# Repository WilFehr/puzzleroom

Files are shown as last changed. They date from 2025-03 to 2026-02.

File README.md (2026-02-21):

# puzzleroom
Inspired by a DND puzzle room where the solution is to be patient and let the timer tick to zero

# what is in this repo?
this repo was started quite late in the development process so was created with the some of the files that will be in the final project

# next step
This project is complete!

# purpose 
the purpose of this project was to:
- gain practial circuit board development experience using KiCad,
- gain more 3D modeling experience using Solidworks
- gain familiarity with the Arduino IDE

# key take aways
I've learned many things from this experience, such as:
- the importance of test points in PCB manufacturing;
  - at some point one LED blew out and it took me a while to figure out that that was the issue and not some other hardware/software issue, having easy access to key circuit points would have made this much faster
- the iterative design nature in engineering;
  - I had many test breadboard circuits before I set up the schematic in KiCad
  - I had many test prints of the base of the housing before I had a design that worked and I was satisfied with.

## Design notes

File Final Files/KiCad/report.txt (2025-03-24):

Info: Processing symbol 'A1:Module:Arduino_Nano'.
Info: Processing symbol 'BZ1:Buzzer_Beeper:Buzzer_12x9.5RM7.6'.
Info: Processing symbol 'D1:LED_THT:LED_D5.0mm_IRGrey'.
Info: Processing symbol 'D2:LED_THT:LED_D5.0mm_IRGrey'.
Info: Processing symbol 'D3:LED_THT:LED_D5.0mm_IRGrey'.
Info: Processing symbol 'D4:LED_THT:LED_D5.0mm_IRGrey'.
Info: Processing symbol 'J1:PPTC021LFBN_RC:CONN2_LFBN-RC_SUL'.
Info: Processing symbol 'R1:Resistor_THT:R_Axial_DIN0207_L6.3mm_D2.5mm_P10.16mm_Horizontal'.
Info: Processing symbol 'R2:Resistor_THT:R_Axial_DIN0207_L6.3mm_D2.5mm_P10.16mm_Horizontal'.
Info: Processing symbol 'R3:Resistor_THT:R_Axial_DIN0207_L6.3mm_D2.5mm_P10.16mm_Horizontal'.
Info: Processing symbol 'R4:Resistor_THT:R_Axial_DIN0207_L6.3mm_D2.5mm_P10.16mm_Horizontal'.
Info: Processing symbol 'R5:Resistor_THT:R_Axial_DIN0207_L6.3mm_D2.5mm_P10.16mm_Horizontal'.
Info: Processing symbol 'R6:Resistor_THT:R_Axial_DIN0207_L6.3mm_D2.5mm_P10.16mm_Horizontal'.
Info: Processing symbol 'SW1:Button_Switch_THT:SW_PUSH_6mm'.
Add A1 (footprint 'Module:Arduino_Nano').
Add BZ1 (footprint 'Buzzer_Beeper:Buzzer_12x9.5RM7.6').
Add D1 (footprint 'LED_THT:LED_D5.0mm_IRGrey').
Add D2 (footprint 'LED_THT:LED_D5.0mm_IRGrey').
Add D3 (footprint 'LED_THT:LED_D5.0mm_IRGrey').
Add D4 (footprint 'LED_THT:LED_D5.0mm_IRGrey').
Add J1 (footprint 'PPTC021LFBN_RC:CONN2_LFBN-RC_SUL').
Add R1 (footprint 'Resistor_THT:R_Axial_DIN0207_L6.3mm_D2.5mm_P10.16mm_Horizontal').
Add R2 (footprint 'Resistor_THT:R_Axial_DIN0207_L6.3mm_D2.5mm_P10.16mm_Horizontal').
Add R3 (footprint 'Resistor_THT:R_Axial_DIN0207_L6.3mm_D2.5mm_P10.16mm_Horizontal').
Add R4 (footprint 'Resistor_THT:R_Axial_DIN0207_L6.3mm_D2.5mm_P10.16mm_Horizontal').
Add R5 (footprint 'Resistor_THT:R_Axial_DIN0207_L6.3mm_D2.5mm_P10.16mm_Horizontal').
Add R6 (footprint 'Resistor_THT:R_Axial_DIN0207_L6.3mm_D2.5mm_P10.16mm_Horizontal').
Add SW1 (footprint 'Button_Switch_THT:SW_PUSH_6mm').

Info: Total warnings: 0, errors: 0.

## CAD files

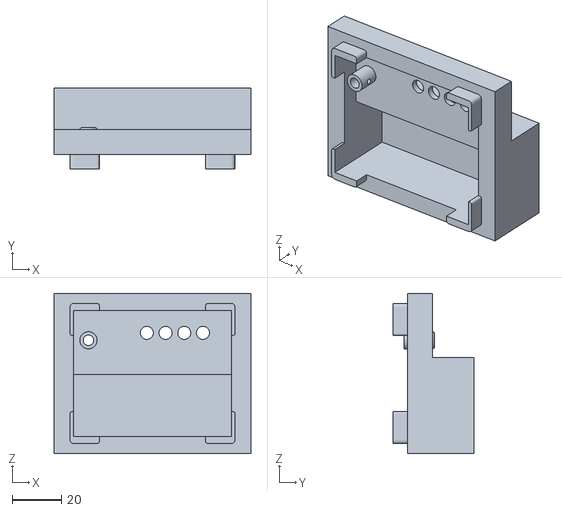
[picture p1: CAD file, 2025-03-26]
STLs/housinglid_complete_draft_V1.STL
80.0 x 33.0 x 65.0

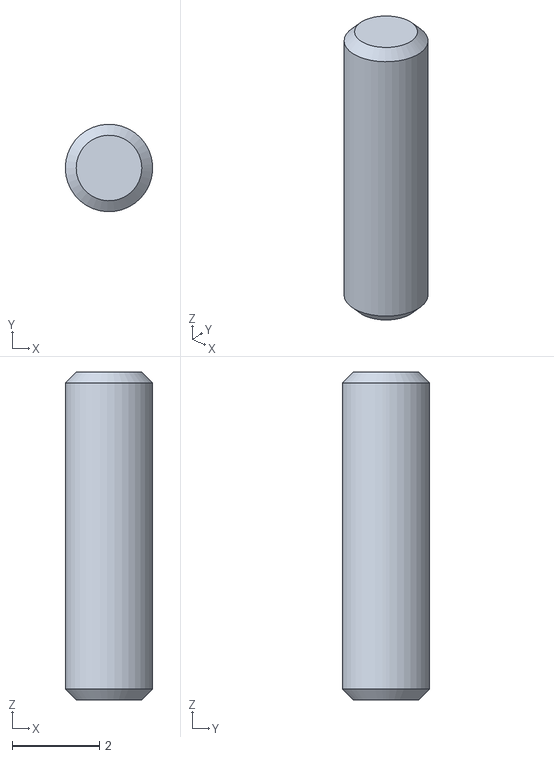
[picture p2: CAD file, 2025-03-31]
Final Files/STLs/locking_peg_FINAL.STL
2.00 x 2.00 x 7.50

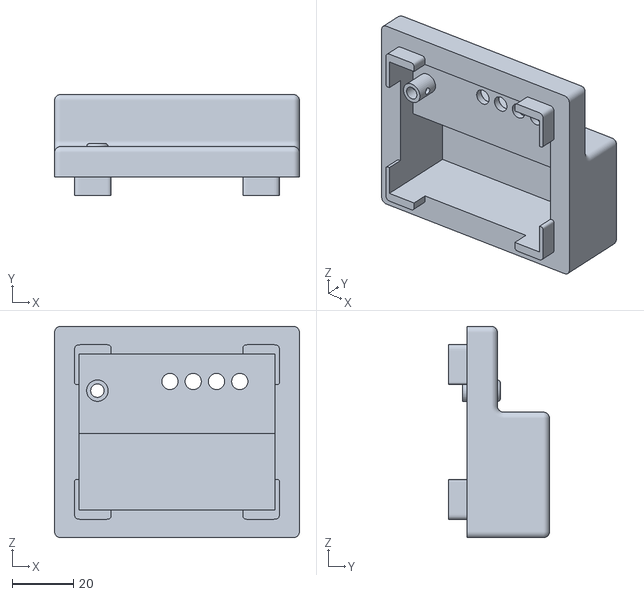
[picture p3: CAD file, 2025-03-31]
Final Files/STLs/housinglid_FINAL.STL
80.0 x 33.0 x 69.0

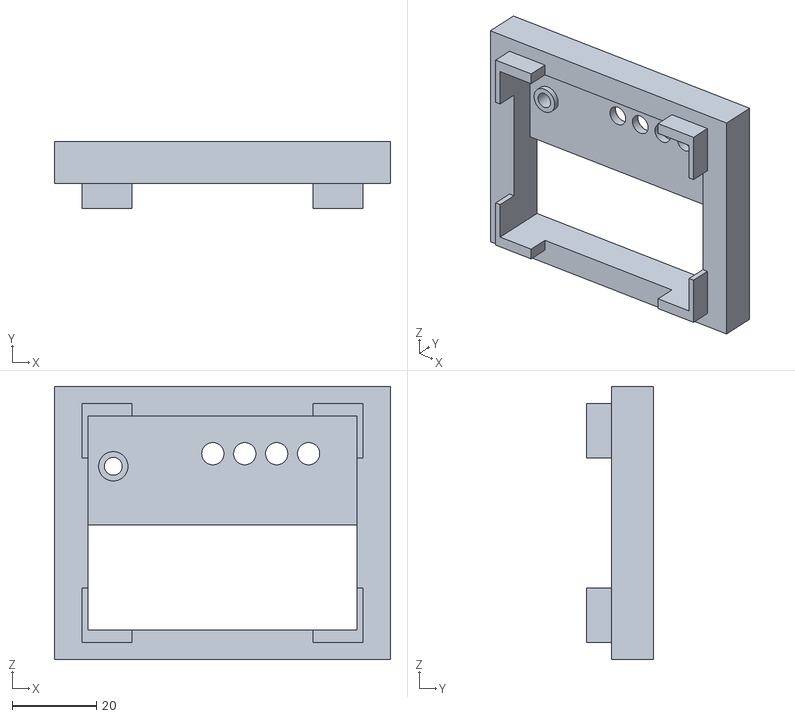
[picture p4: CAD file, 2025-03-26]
STLs/housinglid_lock_check_V2.STL
80.0 x 16.0 x 65.0

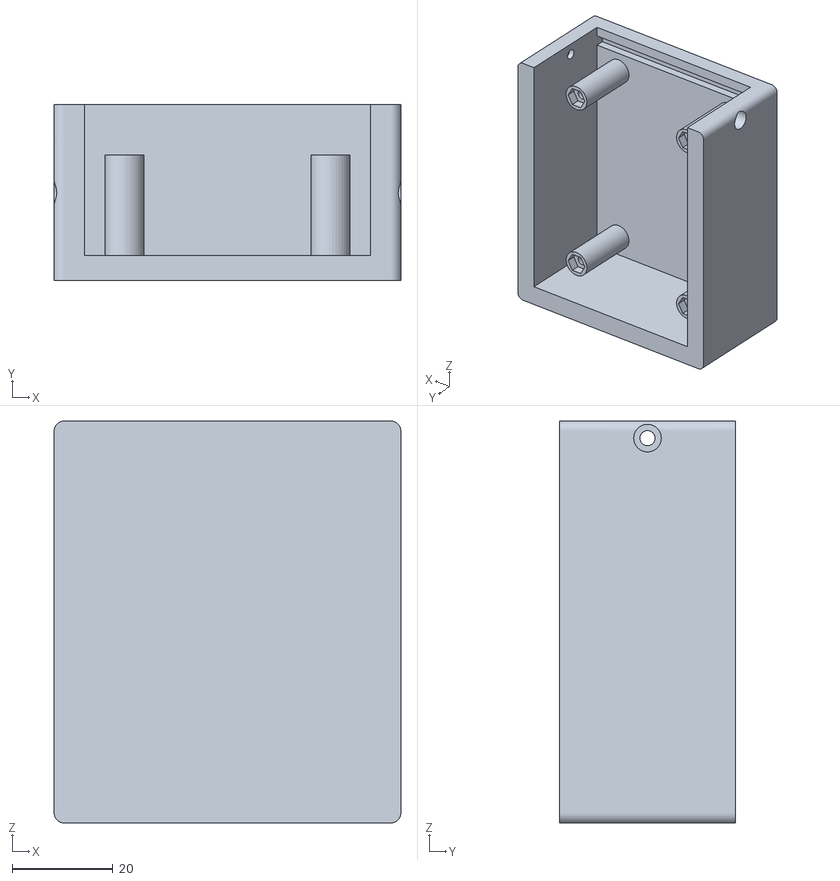
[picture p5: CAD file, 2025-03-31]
Final Files/STLs/housingbase_FINAL.STL
69.0 x 35.0 x 80.0

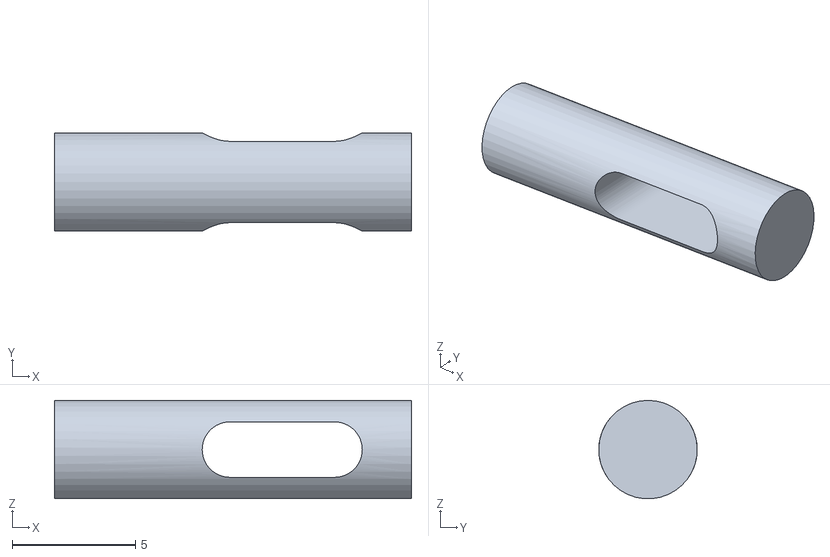
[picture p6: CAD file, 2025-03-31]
Final Files/STLs/Button_peg_FINAL.STL
14.5 x 4.00 x 3.99

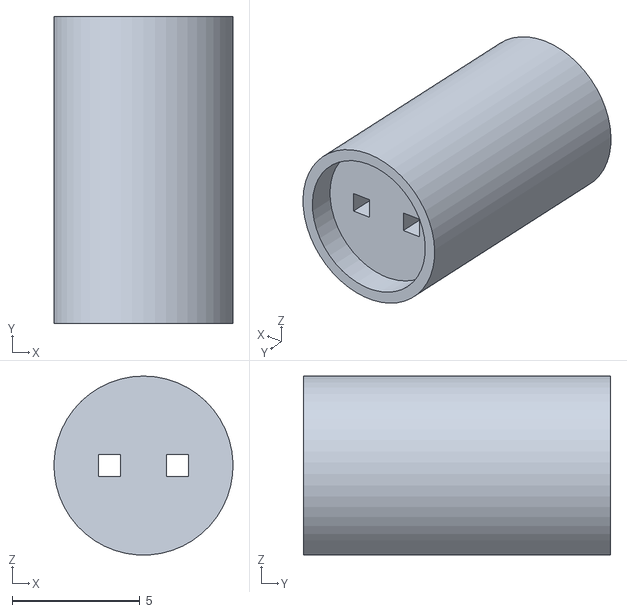
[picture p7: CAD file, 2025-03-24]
Final Files/STLs/ledsupport_FINAL.STL
7.00 x 12.0 x 6.99

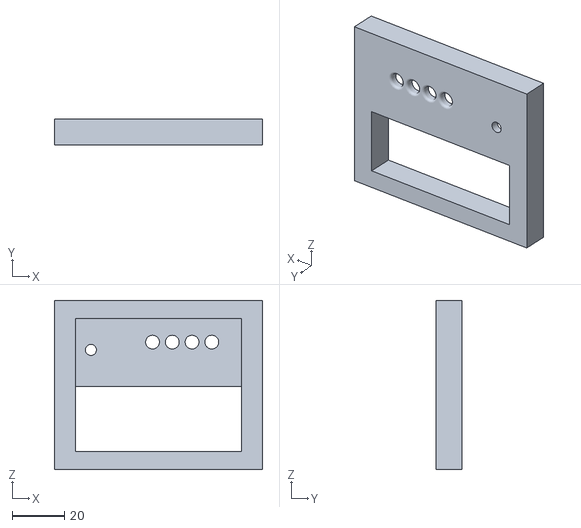
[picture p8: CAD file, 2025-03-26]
STLs/housinglid_Led_and_button_check_V4.STL
80.0 x 10.0 x 65.0

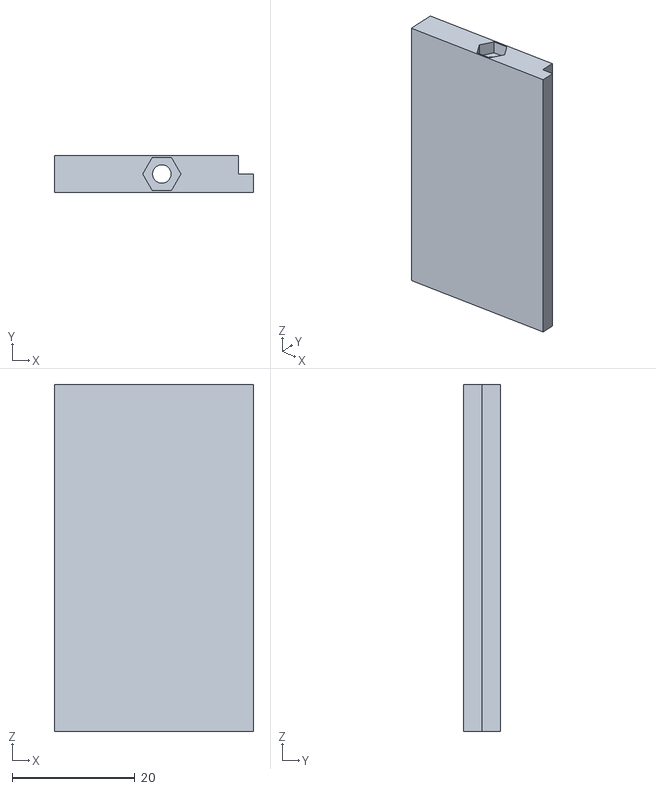
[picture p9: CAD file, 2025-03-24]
Final Files/STLs/housingbase_side_FINAL.STL
32.5 x 6.00 x 56.5

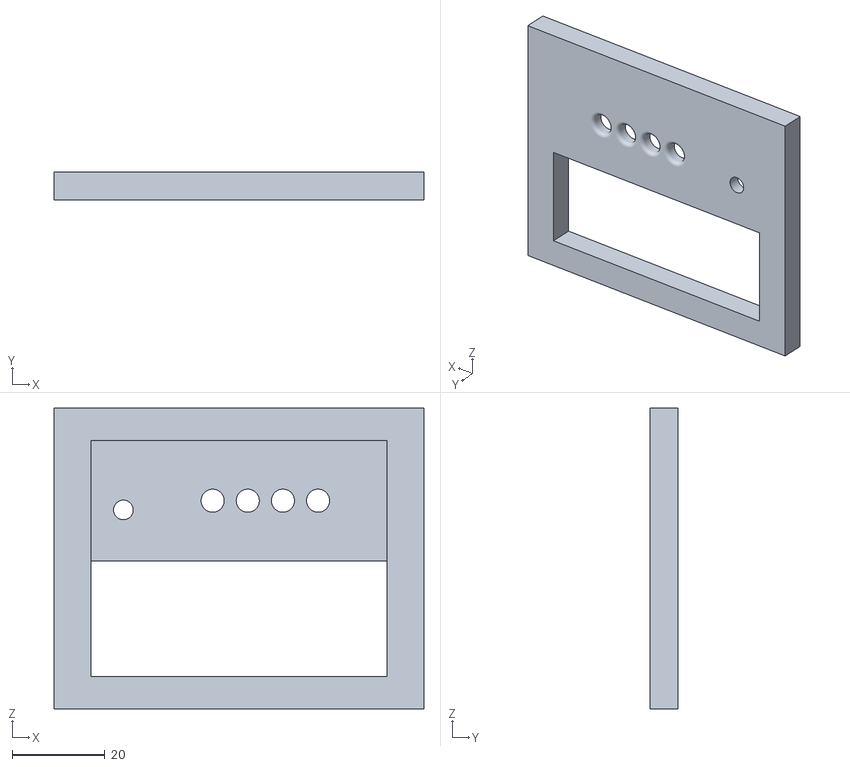
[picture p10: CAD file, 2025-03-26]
STLs/housinglid_led_and_button_check.STL
80.0 x 6.00 x 65.0

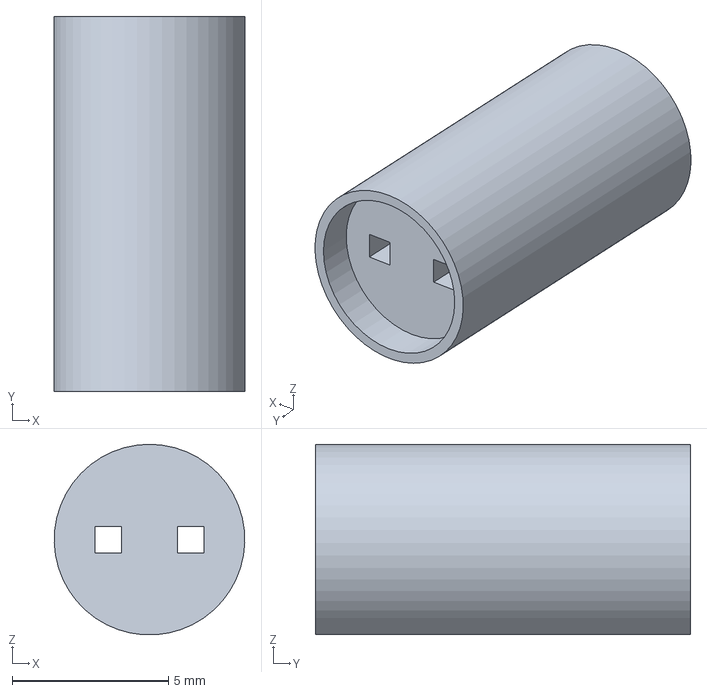
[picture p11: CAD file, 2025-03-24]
STLs/ledsupport.3mf
6.10 x 12.0 x 6.09 mm

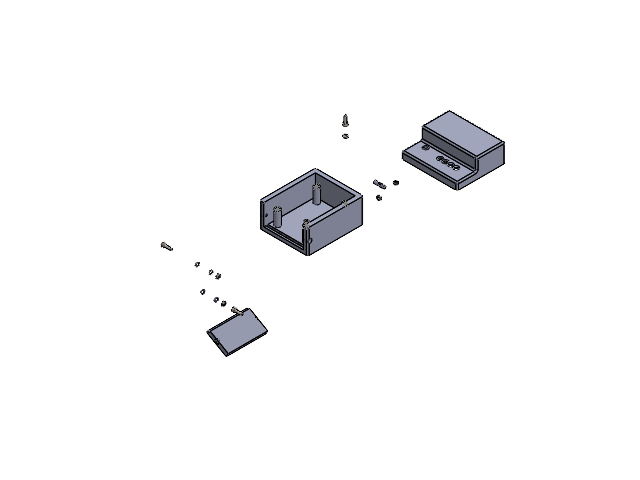
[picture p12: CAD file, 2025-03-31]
Solidworks/PuzzleBox_assembly.SLDASM
Button_peg_V1
housingbase_V3
housingbase_side
housinglid_V3
locking_peg_V1
M3washers x 12
socket head cap screw_iso x 4
hex thin nut chamfered gradeab_iso x 7

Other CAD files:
Solidworks/locking_peg_V1.SLDPRT
Solidworks/housinglid_V3.SLDPRT
Solidworks/housingbase_V3.SLDPRT
Solidworks/Button_peg_V1.SLDPRT
Solidworks/housinglid.SLDPRT
STLs/ledsupport.gcode.3mf
Final Files/STLs/M3washers_FINAL.STL
STLs/housingbase.STL
STLs/housingbase_V2.STL
STLs/housinglid_Led_and_button_check_V2.STL
STLs/housinglid_Led_and_button_check_V3.STL
STLs/housinglid_V2.STL
STLs/housinglid_lock_check_V1.STL
STLs/screwtest.STL
Solidworks/M3washers.SLDPRT
Solidworks/housingbase.SLDPRT
Solidworks/housingbase_V1.SLDDRW
Solidworks/housingbase_V2.SLDPRT
Solidworks/housingbase_side.SLDPRT
Solidworks/housinglid_V2.SLDPRT
Solidworks/pcbmodel.SLDPRT
Solidworks/screwtest.SLDPRT

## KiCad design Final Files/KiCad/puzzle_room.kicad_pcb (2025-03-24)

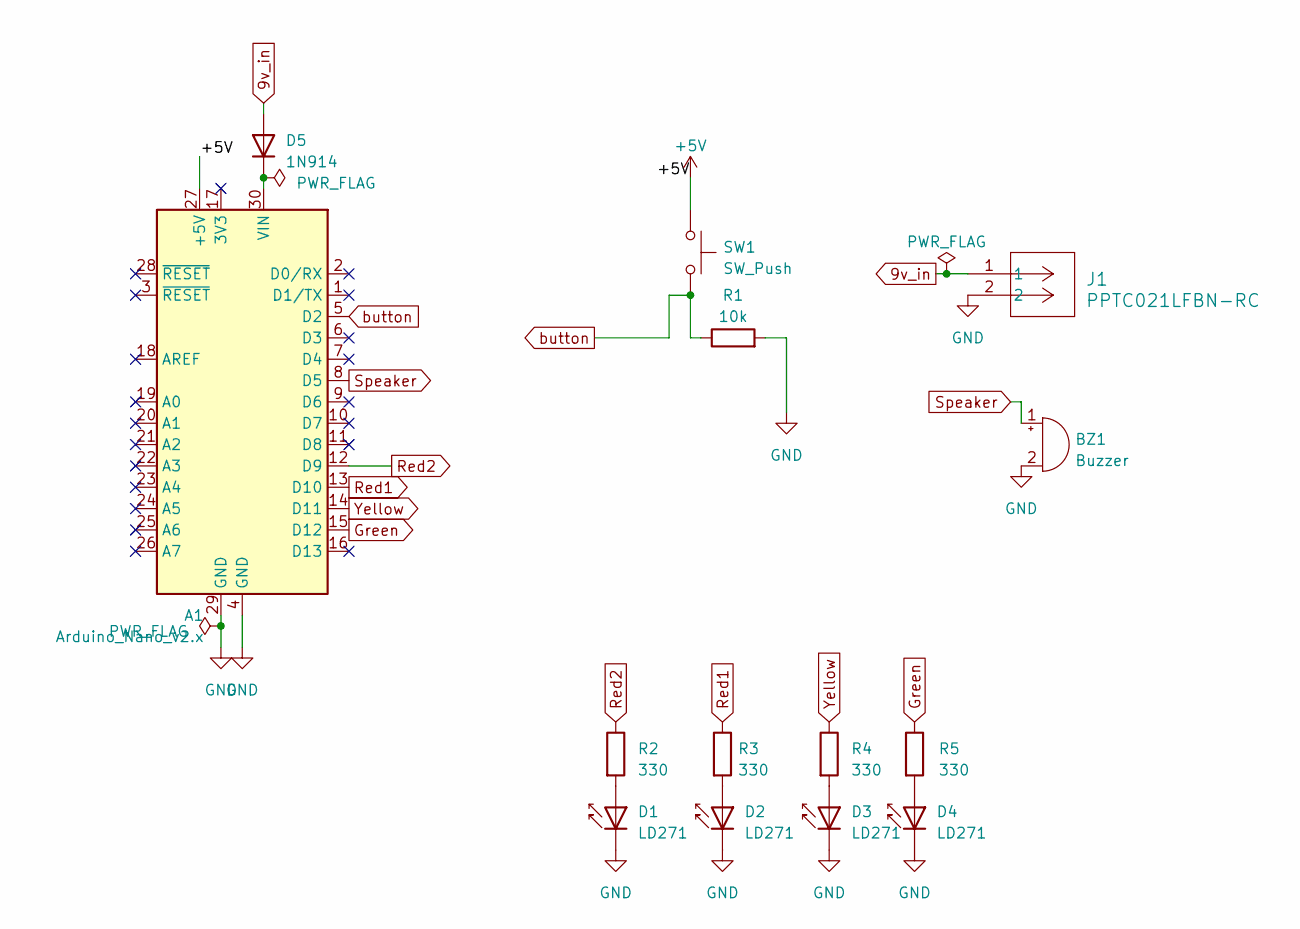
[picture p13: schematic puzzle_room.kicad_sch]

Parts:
A1: Arduino_Nano_v2.x; Arduino_Nano
BZ1: Buzzer; Buzzer_12x9.5RM7.6
D1, D2, D3, D4: LD271; LED_D5.0mm_IRGrey
D5: 1N914; D_DO-35_SOD27_P7.62mm_Horizontal
J1: PPTC021LFBN-RC; CONN2_LFBN-RC_SUL
R1: 10k; R_Axial_DIN0207_L6.3mm_D2.5mm_P10.16mm_Horizontal
R2, R3, R4, R5: 330; R_Axial_DIN0207_L6.3mm_D2.5mm_P10.16mm_Horizontal
SW1: SW_Push; SW_PUSH_6mm

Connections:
9v_in: D5.2 (A), J1.1
+5V: A1.27 (+5V), SW1.1
GND: A1.4 (GND), A1.29 (GND), BZ1.2 (+), D1.1 (K), D2.1 (K), D3.1 (K), D4.1 (K), J1.2, R1.2
Green: A1.15 (D12), R5.1
unnamed: A1.30 (VIN), D5.1 (K)
unnamed: D1.2 (A), R2.2
unnamed: D2.2 (A), R3.2
unnamed: D3.2 (A), R4.2
unnamed: D4.2 (A), R5.2
Red1: A1.13 (D10), R3.1
Red2: A1.12 (D9), R2.1
Speaker: A1.8 (D5), BZ1.1 (-)
Yellow: A1.14 (D11), R4.1
button: A1.5 (D2), R1.1, SW1.2

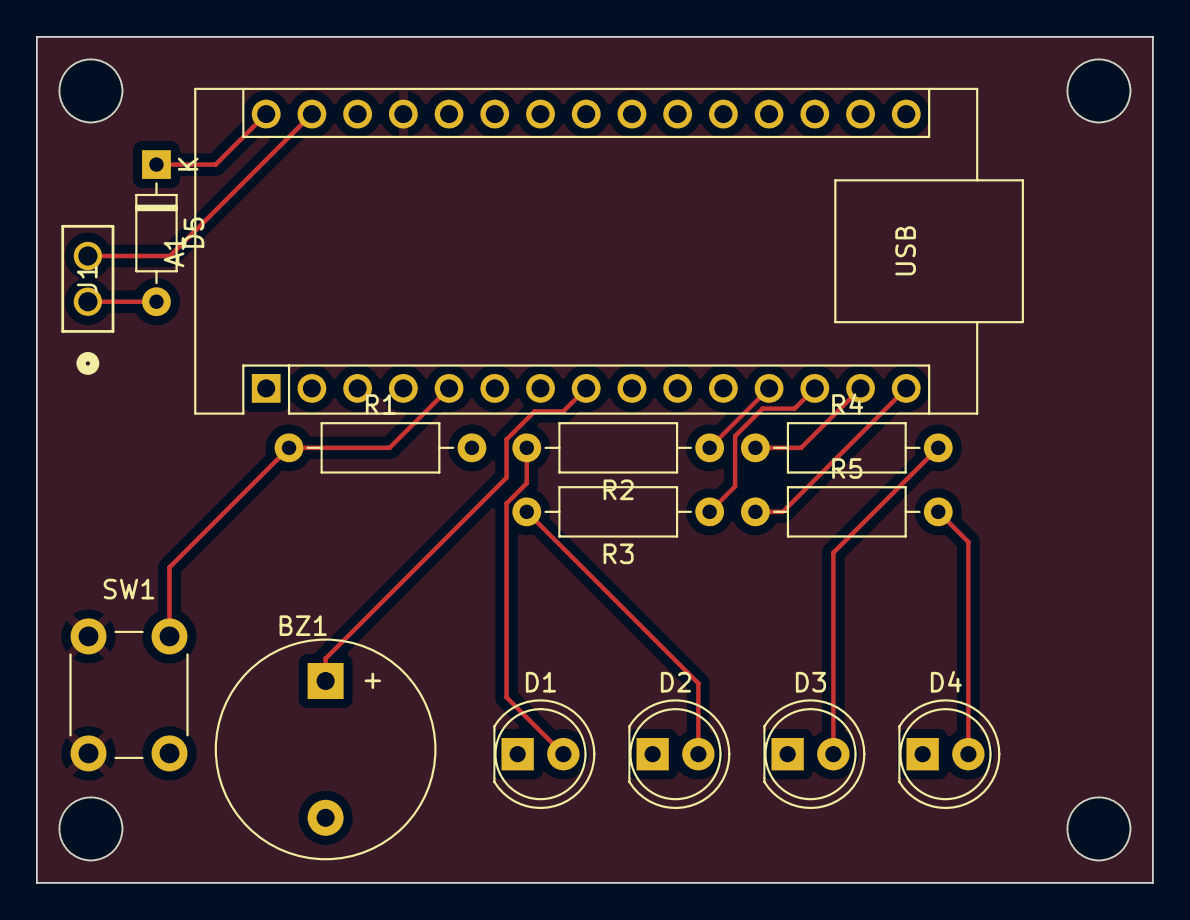
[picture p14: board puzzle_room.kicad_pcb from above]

Board: 2 copper layers, 62.0 x 47.0 mm, 14 parts (0 on the bottom side), 14 nets.

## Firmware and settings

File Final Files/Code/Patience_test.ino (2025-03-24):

// C++ code
//
#define toggle(x) digitalWrite(x, !digitalRead(x));

//const
const int green = 12;
const int yellow = 11;
const int red1 = 10;
const int red2 = 9;
const int button = 2;
const int speaker = 5;

volatile int state = 0;

//debounce code
unsigned long int last_debounce_time = 0;
unsigned long int debounce_delay = 50;//increase if flickers

/*
unsigned long int current_debounce_time = millis();
if ((current_debounce_time - last_debounce_time) > debounce_delay){
	//stuff in here
}
last_debounce_time = current_debounce_time;
*/


const int maxtime = 30;//max time in sec
int max_ms = maxtime*1000; // max time in ms
int max_iter = maxtime*100;
unsigned long int start_of_timer = millis();//start of program


void setup()
{
   pinMode(green, OUTPUT);
  pinMode(yellow, OUTPUT);
  pinMode(red1, OUTPUT);
  pinMode(speaker, OUTPUT);
  pinMode(red2, OUTPUT);
  pinMode(button, INPUT_PULLUP);
  attachInterrupt(digitalPinToInterrupt(button), next, RISING);

}

//change value represents time between toggles.
int place_holder = 1;

void loop()
{
  switch(state){
    case 0:
    digitalWrite(green, 1);
    digitalWrite(yellow, 0);
    digitalWrite(red2, 0);
    digitalWrite(red1, 0);
    digitalWrite(speaker, 1);
    state = 1;
    //green
      //0.33*max_iter
      for (int t = 0; t < 10; t++){
        //delay between toggles
        for(int i = 0; i < max_iter*0.033; i++){//10 ms per iteration
          delay(10);
          if(state == 0)
            break;
        }
        if(state == 0)
            break;
        //toggle
        toggle(green);
        toggle(speaker);
      //
      }//end of green
      if(state == 0)
            break;
      //turn green off
      digitalWrite(green, 0);
      digitalWrite(speaker, 0);


    //yellow
      //0.27*max_iter
      for (int t = 0; t < 10; t++){
        //toggle
        toggle(yellow);
        toggle(speaker);
        //delay between toggles
        for(int i = 0; i < max_iter*0.027; i++){//10 ms per iteration
          delay(10);
          if(state == 0)
            break;
        }
        if(state == 0)
            break;
        

      //
      }//end of yellow
      if(state == 0)
            break;
      //turn yellow off
      digitalWrite(yellow, 0);
      digitalWrite(speaker, 0);

    //red1
      //0.20*max_iter
      for (int t = 0; t < 10; t++){
        //toggle
        toggle(red1);
        toggle(speaker);
        //delay between toggles
        for(int i = 0; i < max_iter*0.02; i++){//10 ms per iteration
          delay(10);
          if(state == 0)
            break;
        }
        if(state == 0)
            break;
        

      //
      }//end of red1
      if(state == 0)
            break;
      //turn red1 off
      digitalWrite(red1, 0);
      digitalWrite(speaker, 0);

    //red2
      //0.13*max_iter
      for (int t = 0; t < 10; t++){
        //toggle
        toggle(red2);
        toggle(speaker);
        //delay between toggles
        for(int i = 0; i < max_iter*0.013; i++){//10 ms per iteration
          delay(10);
          if(state == 0)
            break;
        }
        if(state == 0)
            break;
        

      //
      }//end of red2
      if(state == 0)
            break;
      //turn red2 off
      //digitalWrite(red2, 0);

    //red flash
      //0.07*max_iter
      for (int t = 0; t < 10; t++){//number of toggles
        //toggle
        toggle(red2);
        toggle(red1);
        toggle(speaker);
        //delay between toggles
        for(int i = 0; i < max_iter*0.007; i++){//10 ms per iteration
          delay(10);
          if(state == 0)
            break;
        }
        if(state == 0)
            break;
      //
      }//end of red flash
      if(state == 0)
            break;
      //turn red off
      digitalWrite(red2, 0);
      digitalWrite(red1, 0);
      digitalWrite(speaker, 0);

    int end_cycle1 [8] = { 12, 12, 11, 11, 10, 10, 9, 9};
    int end_cycle2 [8] = { 12, 11, 10, 9, 12, 11, 10, 9};

    //celebration
    for (int h = 0; h < 3; h++){
      for (int k = 0; k < 8; k++){//go through end cycle 1
        for(int i = 0; i < max_iter*0.01; i++){//10 ms per iteration
          delay(10);
          if(state == 0)
            break;
        }
        if(state == 0)
            break;
        //toggle
        toggle(end_cycle1[k]);
      }//end of celebration cycle 1
      if(state == 0)
        break;    
    }
    if(state == 0)
      break;

    //celebration
    for (int h = 0; h < 3; h++){
      for (int k = 0; k < 8; k++){//go through end cycle 1
        for(int i = 0; i < max_iter*0.01; i++){//10 ms per iteration
          delay(10);
          if(state == 0)
            break;
        }
        if(state == 0)
            break;
        //toggle
        toggle(end_cycle2[k]);
      }//end of celebration cycle 1
      if(state == 0)
        break;    
    }
    if(state == 0)
      break;


    default:
      //


      digitalWrite(green, 1);
      digitalWrite(yellow, 1);
      digitalWrite(red2, 1);
      digitalWrite(red1, 1);
      break;
  }
}

void next(){
  unsigned long int current_debounce_time = millis();
  if ((current_debounce_time - last_debounce_time) > debounce_delay){
      //stuff in here
    state = 0;
  }
  last_debounce_time = current_debounce_time;
};

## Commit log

2025-03-24 updating the github with the project so far
    [M3washers.SLDPRT, M3washers.STL, housingbase.SLDPRT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]
2025-03-25 starting the lid
    [housinglid.SLDPRT]
2025-03-26 lid fit test files
    checking the fit of the LEDs in the lid and first draft of the locking mechanism
    [housinglid.SLDPRT, housinglid_Led_and_button_check_V2.STL, housinglid_Led_and_button_check_V3.STL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]
2025-03-26 the lid draft 1
    the first complete draft of the lid
    [housinglid.SLDPRT, housinglid_complete_draft_V1.STL, housinglid_lock_check_V2.STL]
2025-03-31 finalized the housing design and starting project wrap up
    finished the housing designs and am starting the process of collecting the final versions of the all the files, making the solidworks assembly and drawings.
    [Button_peg_FINAL.STL, Button_peg_V1.SLDPRT, Button_peg_V1.STL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]
